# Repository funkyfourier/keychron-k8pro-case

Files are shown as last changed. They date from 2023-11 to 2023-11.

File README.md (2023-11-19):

# WIP: 3D Printable Case for the Keychron K8 Pro keyboard

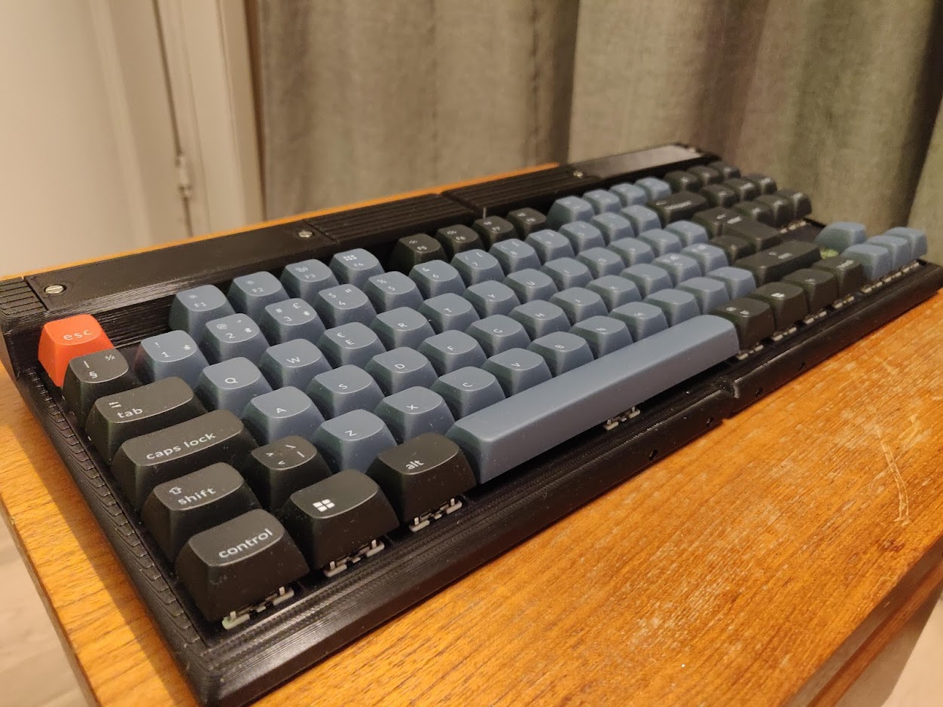
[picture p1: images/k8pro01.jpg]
Keychron K8 Pro with 3D printed case


When I got me a [Keychron K8 Pro](https://www.keychron.com/collections/keychron-k-pro-series-normal-profile-keyboards/products/keychron-k8-pro-qmk-via-wireless-mechanical-keyboard) I liked everything about it except the height. Having some CAD skills and a 3D printer I therefore set out to design my own custom case.

It has taken way much more time than I thought and is basically a product of [the sunken cost fallacy](https://en.wikipedia.org/wiki/Sunk_cost#Fallacy_effect). Still, I ended up with something I really liked and overall it has been a fun experience.

### Disclaimer

*This is to be regarded as a work in progress*, since there still are some [issues](https://github.com/funkyfourier/keychron-k8pro-case/issues) which you should be aware of before attempting to print this. At the time of writing I am not sure how much more time I am going to put into this since it already has stolen a lot of valuable time from my [other](https://github.com/funkyfourier/spitback) [projects](https://play.google.com/store/apps/details?id=info.casualcomputing.sputter).

**Important:** I have **not** dared testing using the battery yet since I do not need it personally. According to the text on the charging chip it uses the TP5000X charging IC, which I have included the [data sheet](https://github.com/funkyfourier/keychron-k8pro-case/blob/master/tp5000x.pdf) for. I am quite confident that it will work, but **do not blame me if it does not**. Also, if you need the battery, beware of [issue#7](https://github.com/funkyfourier/keychron-k8pro-case/issues/7).

**Also:** Pay attention to the polarity when you insert the battery. I do *not* know wether the board has reverse polarity protection, and the board could get fried if you insert the battery the wrong way.

### Advantages:

* Probably as low profile as it can get with a PCB and hot swap sockets.
* USB connector on backside.
* Labels for the PC/Mac and BT/Cable switches are actually visible without a lamp and magnifying glass.
* More visible screws, which is masculine and cool.
* Replaceable battery.
* Possibly better looking, depending on your taste, than the aluminium frame which [some find to be hideous](https://youtu.be/LNVKRTX5gCQ?t=504).

### Drawbacks:

* Won't do any favors to the sound of the keyboard.
* No flip out feet to adjust angle.
* Increased depth due to the compartment housing the battery and daughter board.

### In use

Even with the remaining [issues](https://github.com/funkyfourier/keychron-k8pro-case/issues) unsolved, I am quite enjoying using this as my main keyboard. Obviously it does not sound as good as in the original case, mostly due to the lack of dampening materials. On the other hand the relatively low profile without having to resort to a wrist rest and still having full travel keys makes for a pretty great experience. I have tried a [K3 Pro](https://www.keychron.com/products/keychron-k3-pro-qmk-via-wireless-custom-mechanical-keyboard) at work and definetely like this better.

Of course getting the [Keychron V3 QMK](https://www.keychron.com/products/keychron-v3-qmk-custom-mechanical-keyboard) instead is a more sensible option. I was not aware of it at the time I got my K8 Pro. Still, having the option to switch to bluetooth for my work laptop while the keyboard is plugged into my PC, and being able to switch between them quickly, is a great convenience. The V3 is probably also a couple of millimeters taller.

### Printing and assembly

The case is made in [FreeCAD](https://www.freecad.org/). If you want to adjust dimensions it should be sufficient to do that in the spreadsheets.

All parts should be printable without supports. Please rotate the models to the correct orientation in the slicer before printing.

The daughter board cover is printed with a pause command which can be set in the slicer to change the color while printing. This allows for the letters being printed in another color. If your slicer/printer does not support that the letters should still be visible.

### Bill Of Materials

* 6 M3 machine screws, max 11mm length excluding head, and max 6mm head diameter.
* 6 M3 threaded inserts.
* 4 M2 machine screws, max 5mm length excluding head, and max 3mm head diameter.
* 4 wood screws. Not quite sure about the dimensions, but mine are 4mm in diameter across the threads, 19mm length excluding head and head diameter of 8mm.
* 20mm x 5mm x 1.5mm self adhesive rubber feet
* A 21700 battery of well known brand like Molicel or Samsung.
* A 21700 battery holder [like this](https://vi.aliexpress.com/item/1005004464947052.html?spm=a2g0o.productlist.main.15.70155b8eZTWrik). **See first:** [issue#7](https://github.com/funkyfourier/keychron-k8pro-case/issues/7)
* One 2 pin ZH 1.5 JST connector [like this](https://vi.aliexpress.com/item/1005003082340140.html?spm=a2g0o.order_list.order_list_main.27.124e18027wA48)
* Cables to go from battery holder to daughter board.

## Pics

Please excuse the dust. It is amazing how clean things can look in person while lots of dust and debris still show up on camera.

**Side profile:**

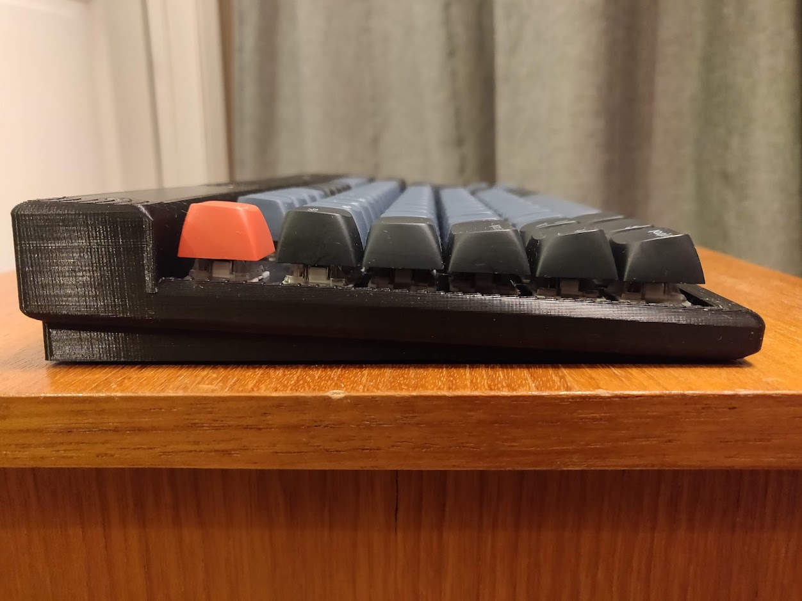
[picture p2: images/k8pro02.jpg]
Side profile


**Back side:**

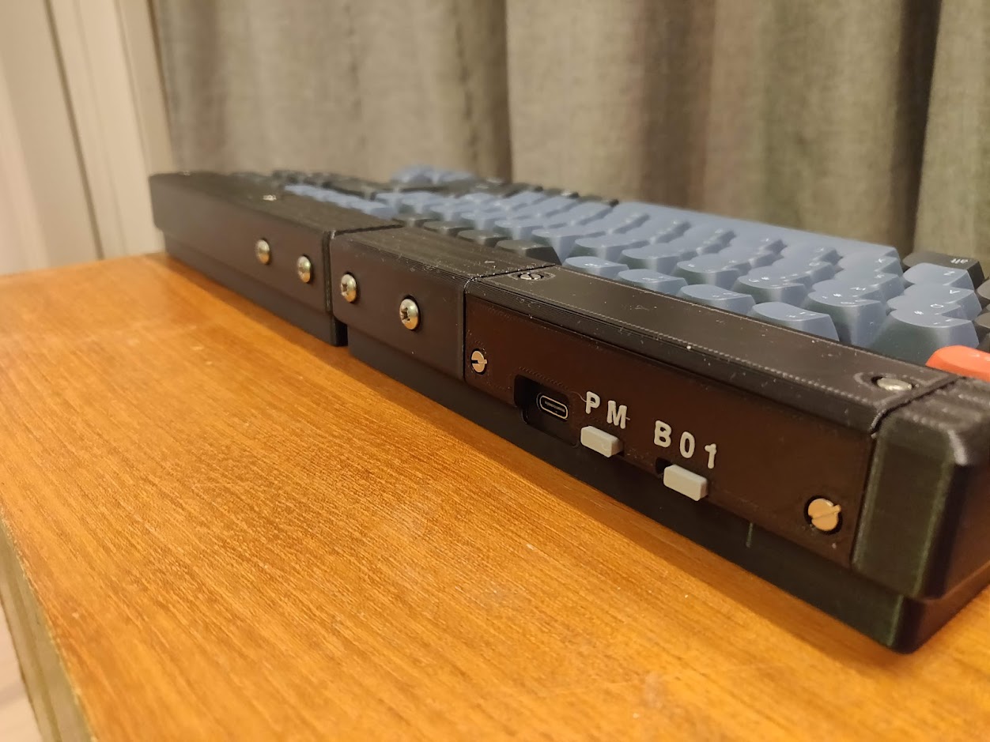
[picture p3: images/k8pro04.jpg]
Back side


**Front screws:**

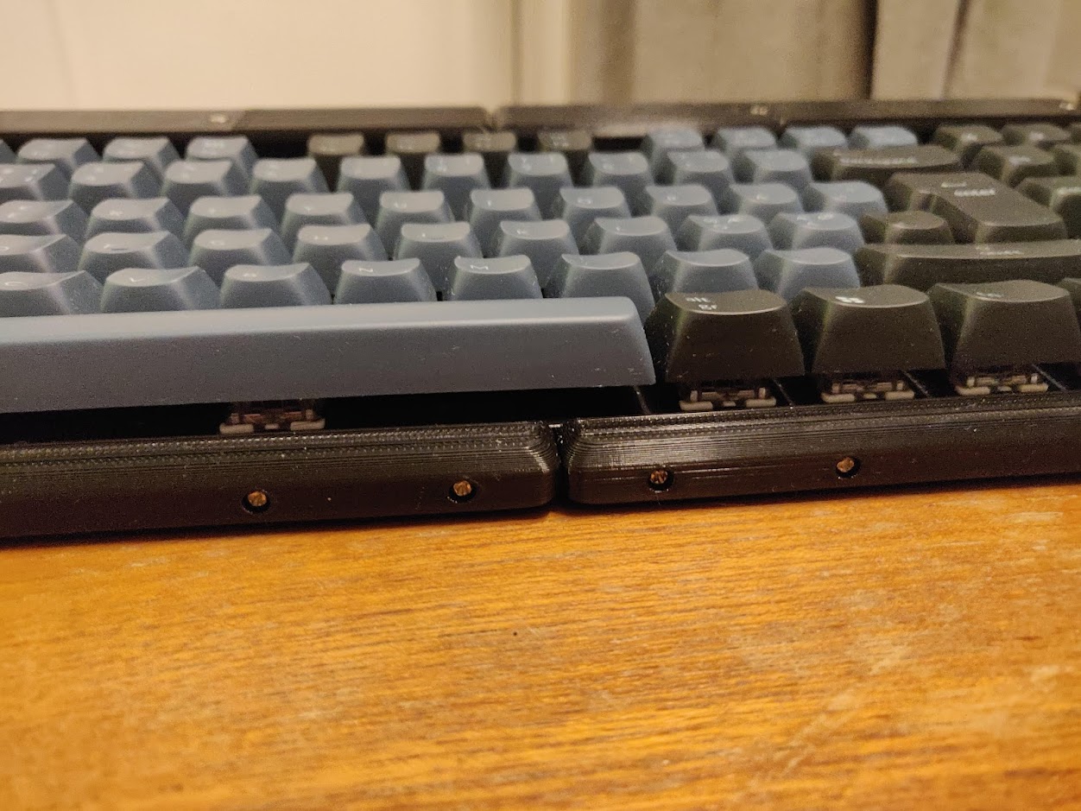
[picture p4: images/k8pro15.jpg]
Front screws


**USB plug and switches:**

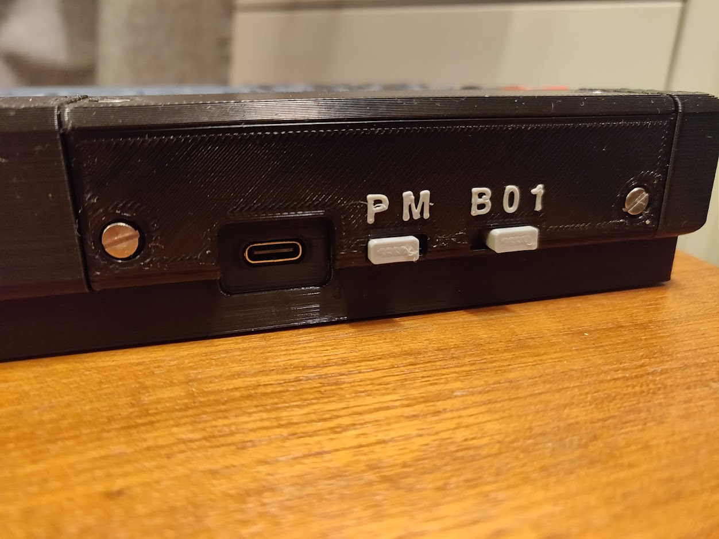
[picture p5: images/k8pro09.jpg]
USB plug and switches


**PCB partly exposed underneath:**

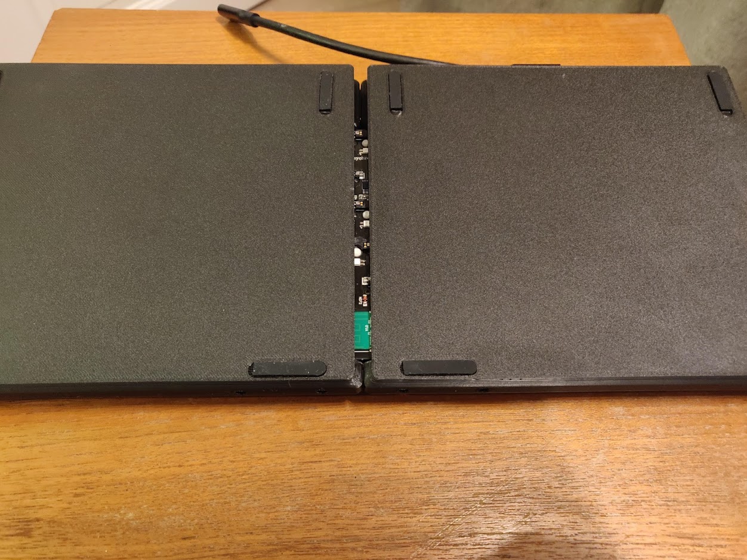
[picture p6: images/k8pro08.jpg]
PCB partly exposed underneath


**Battery compartment:**

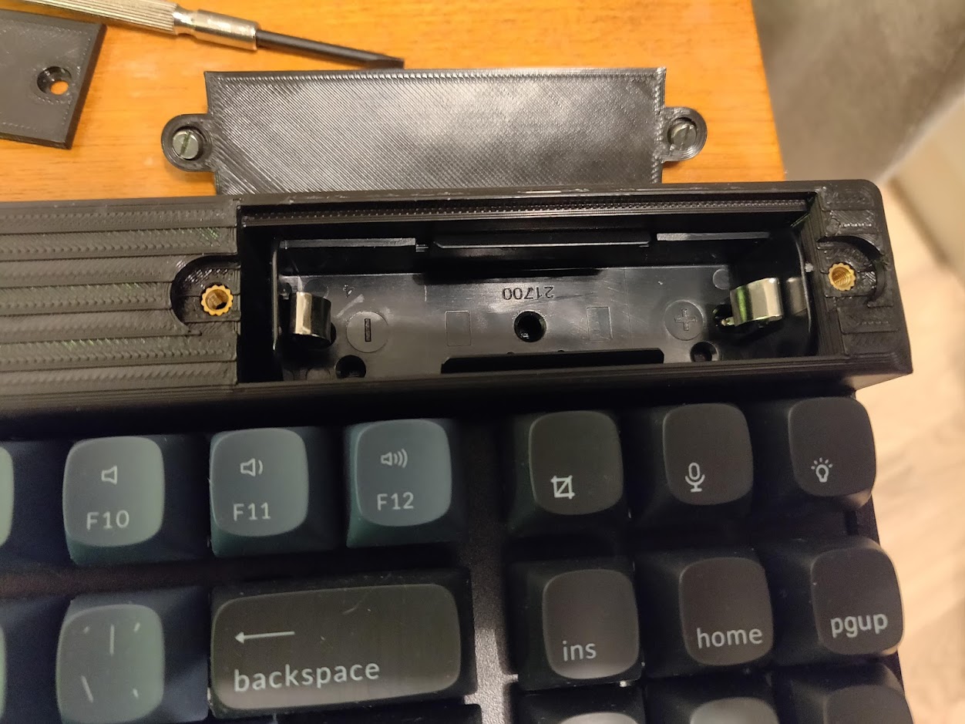
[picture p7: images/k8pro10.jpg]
Battery compartment


**Daughter board compartment:**

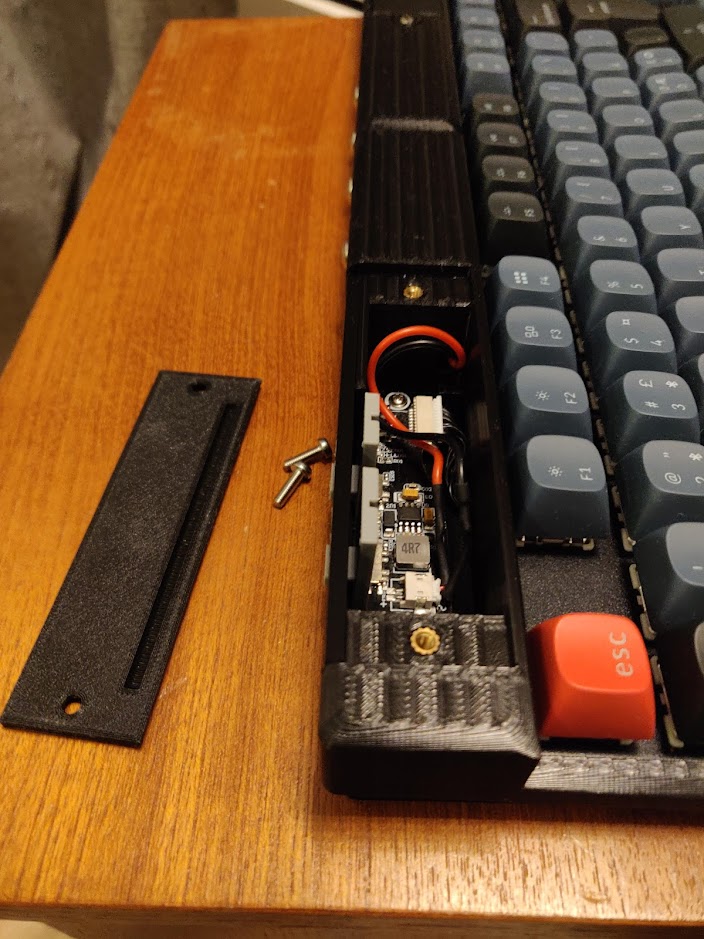
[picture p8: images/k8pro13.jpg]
Daughter board compartment


**Surface finish front:**

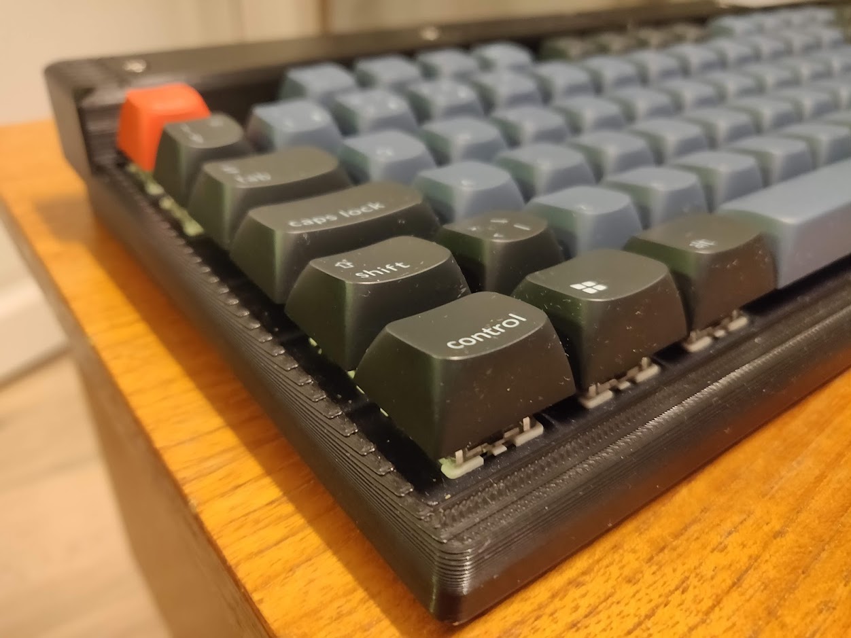
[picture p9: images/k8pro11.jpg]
Surface finish front


**Surface finish backside:**

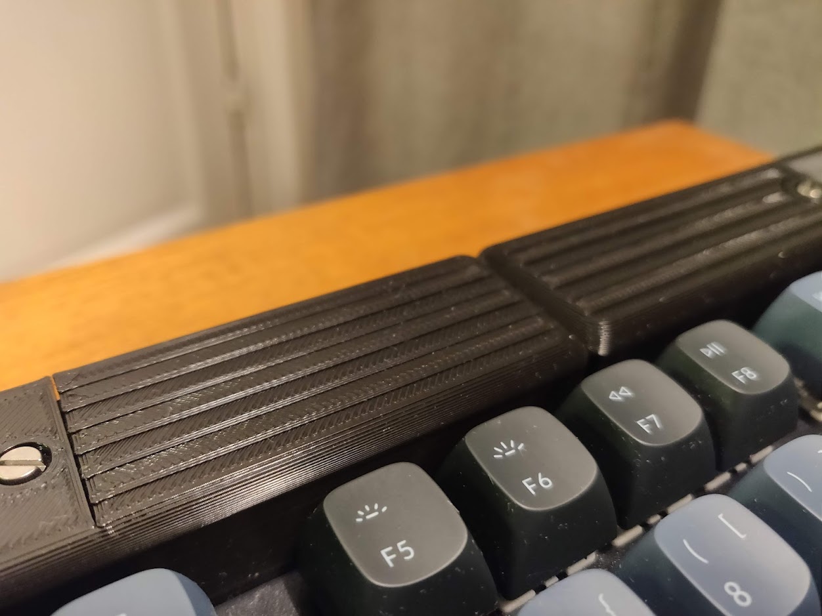
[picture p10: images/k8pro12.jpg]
Surface finish backside


**In FreeCAD, in all its glory:**

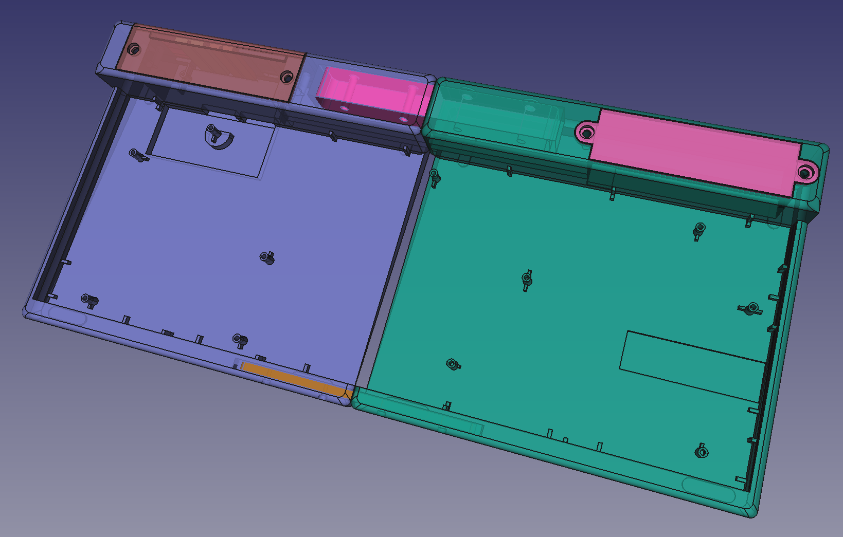
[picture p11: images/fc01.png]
In FreeCAD, in all its glory


**In FreeCAD, from behind:**

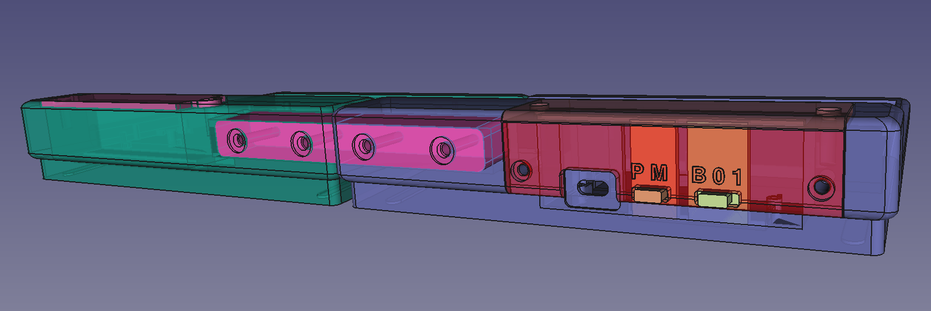
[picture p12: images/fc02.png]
In FreeCAD, from behind


**In FreeCAD, daughter board compartment:**

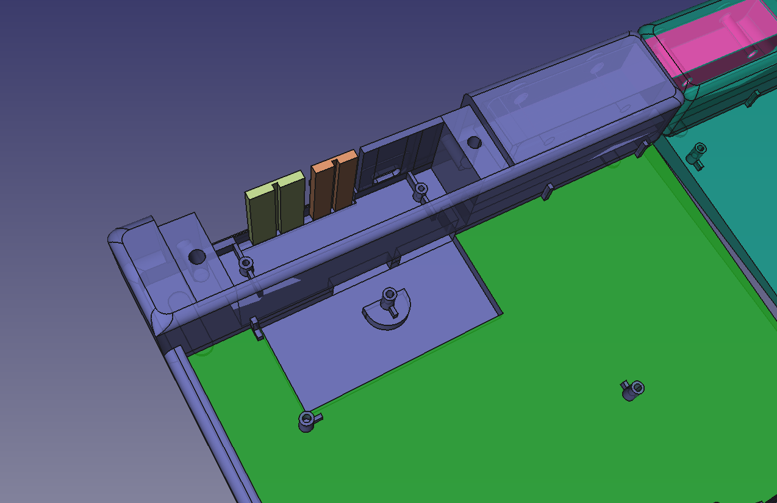
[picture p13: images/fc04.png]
In FreeCAD, daughter board compartment


**In FreeCAD, gap underneath:**

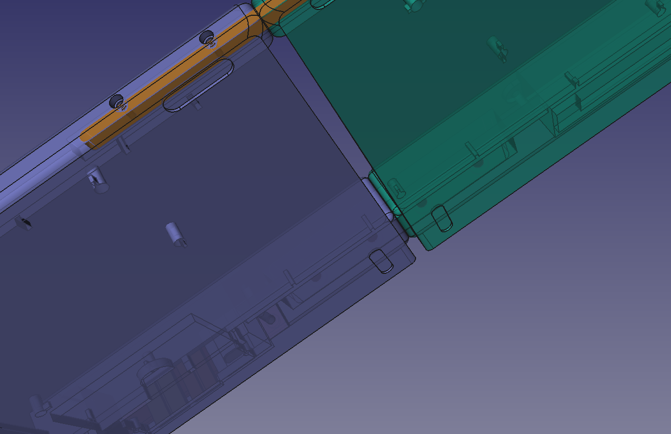
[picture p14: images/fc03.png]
In FreeCAD, gap underneath


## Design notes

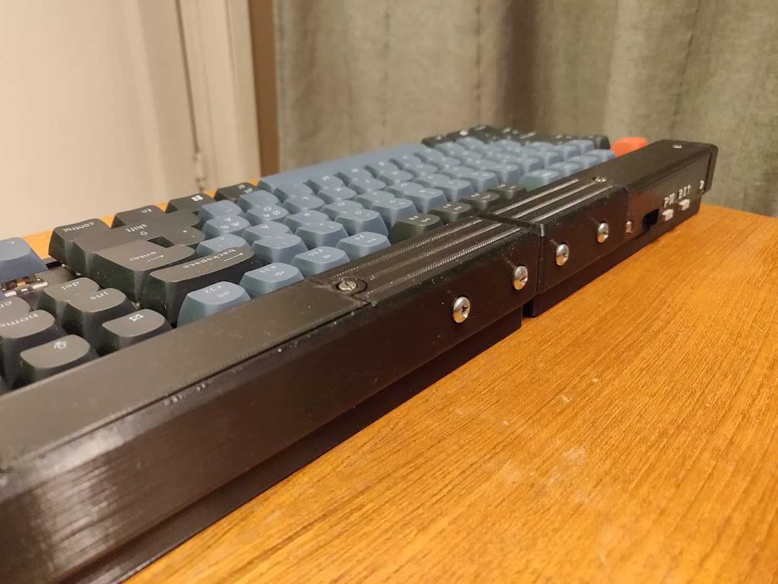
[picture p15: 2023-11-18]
images/k8pro03.jpg

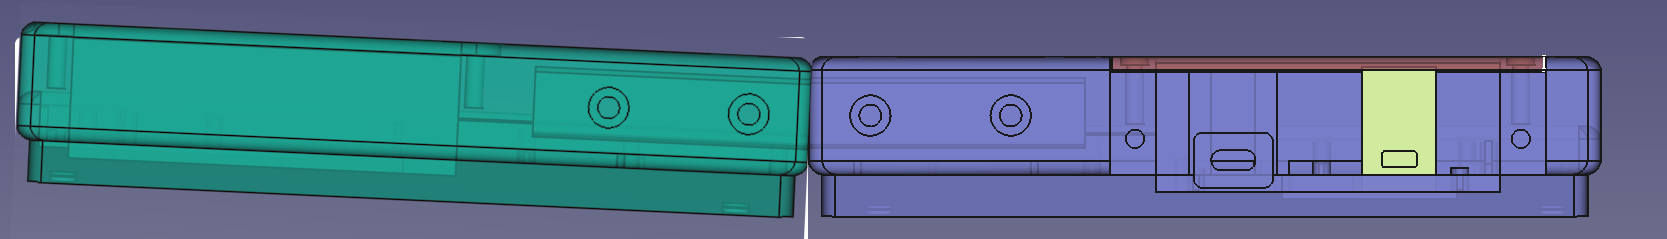
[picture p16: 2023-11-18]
images/skewed_halves.png

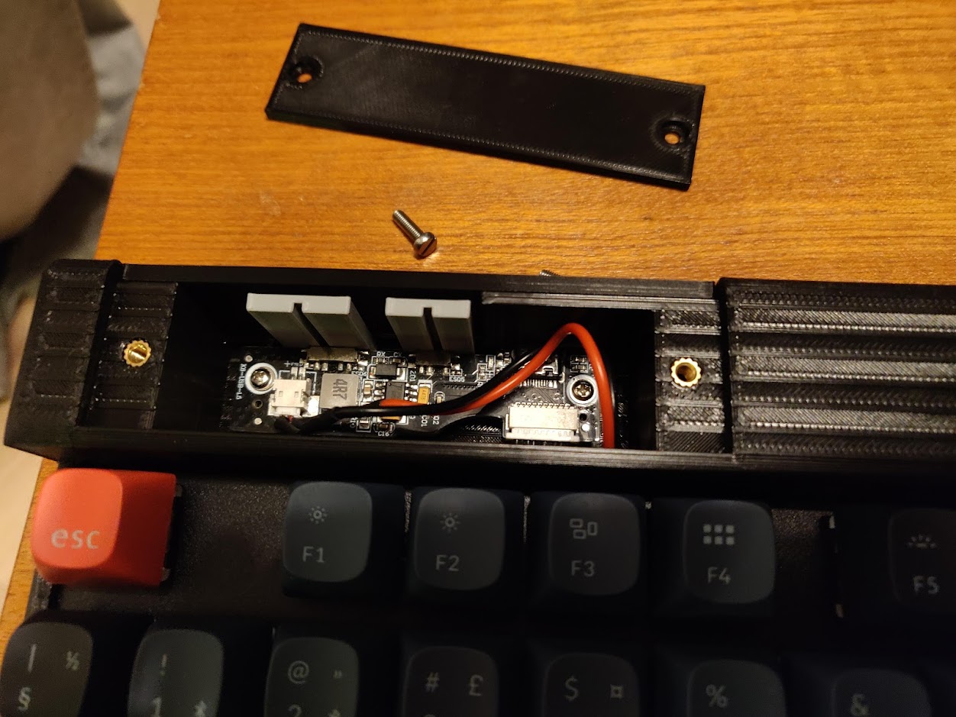
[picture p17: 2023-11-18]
images/k8pro07.jpg

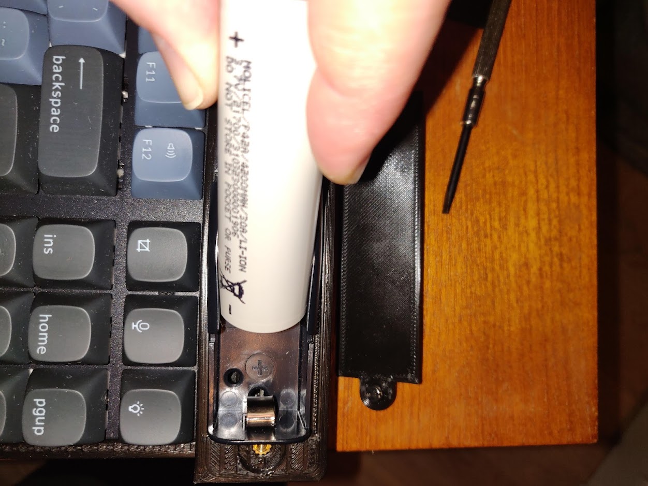
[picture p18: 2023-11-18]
images/k8pro14.jpg

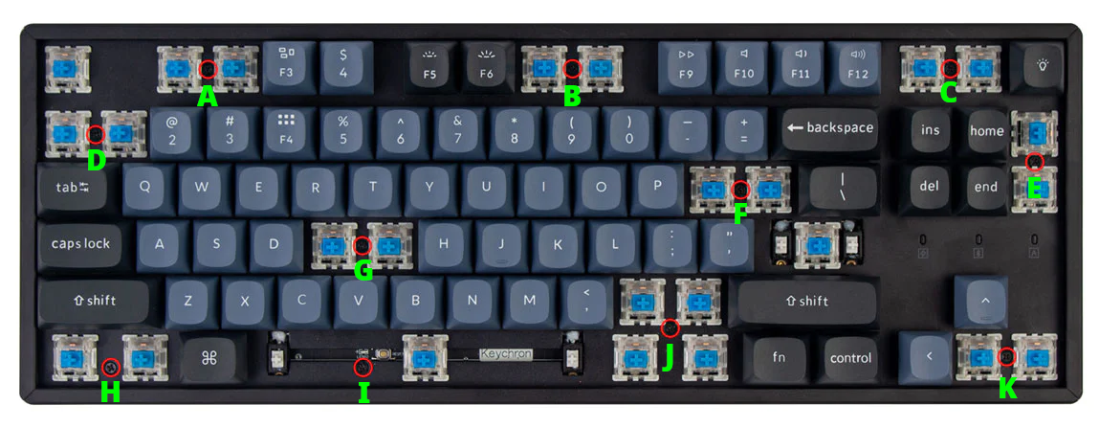
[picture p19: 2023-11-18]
k8proscrewposition.png

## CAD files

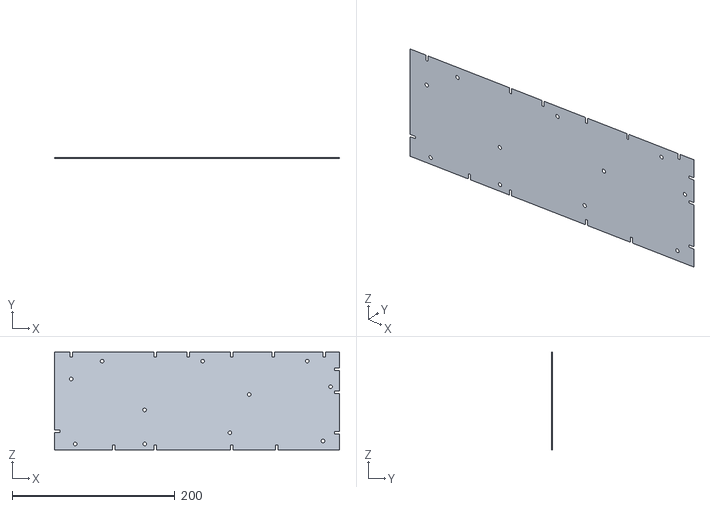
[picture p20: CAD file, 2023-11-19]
stl/DimensionsTestEdgePlate.stl
350.0 x 0.72 x 120.0

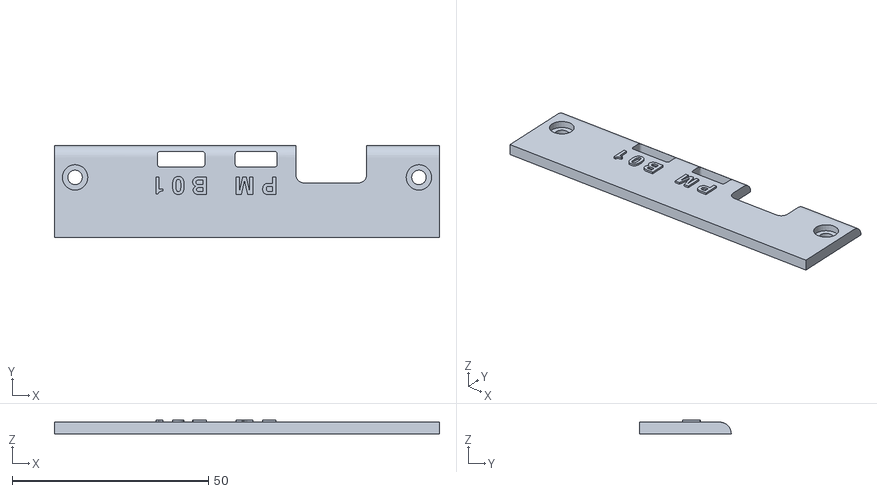
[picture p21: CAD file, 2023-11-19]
stl/DaughterboardLidBottom.stl
98.2 x 23.4 x 3.50

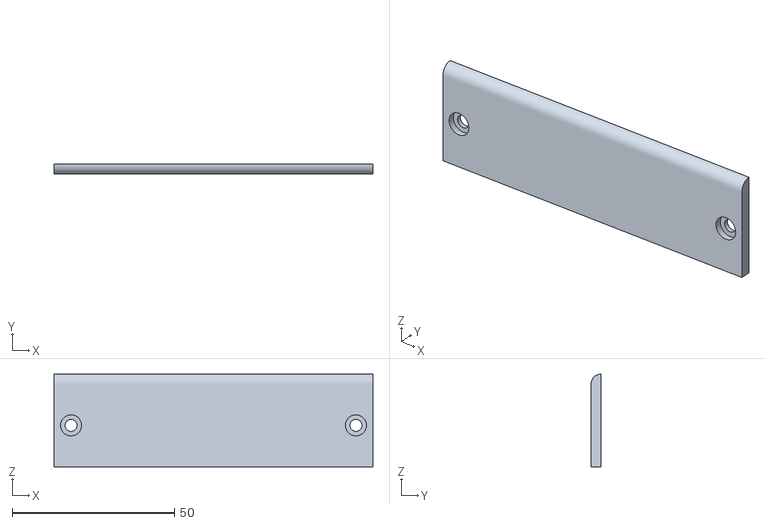
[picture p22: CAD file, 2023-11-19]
stl/DaughterboardLidTop.stl
98.2 x 3.00 x 28.6

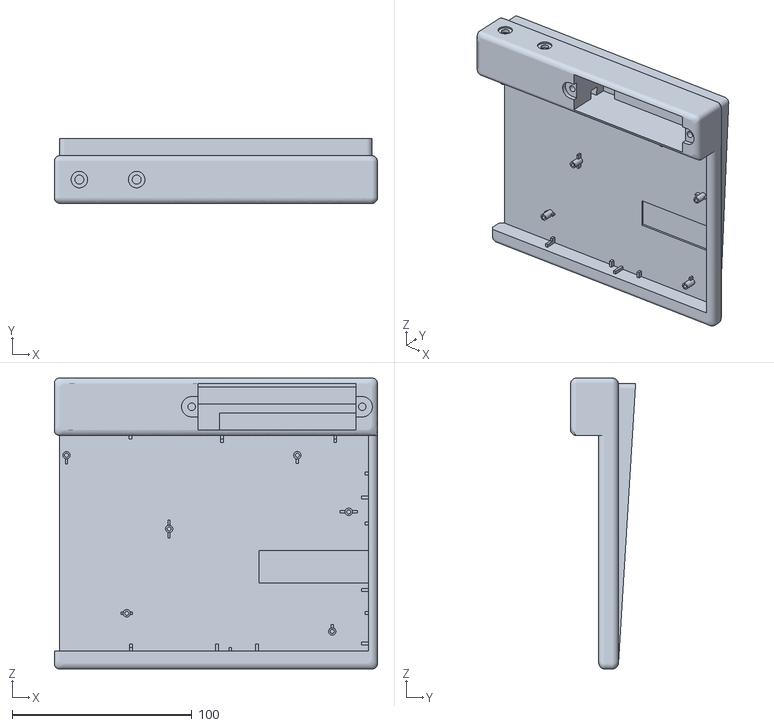
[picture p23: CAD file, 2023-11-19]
stl/BaseRight.stl
179.9 x 36.3 x 162.0

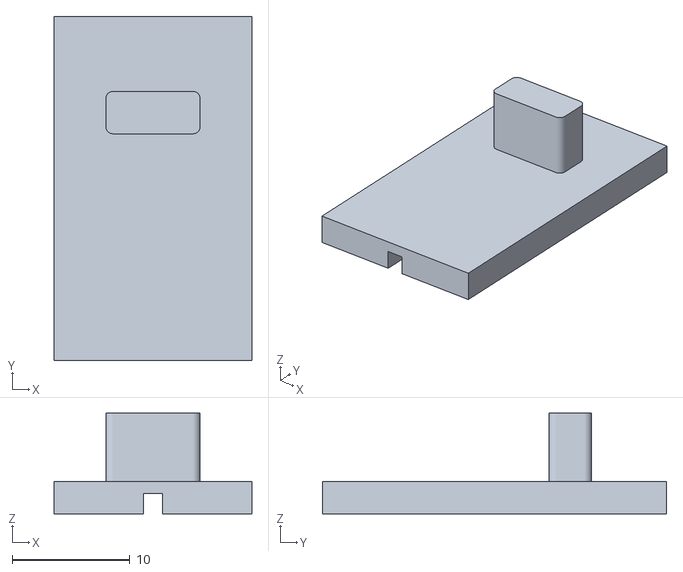
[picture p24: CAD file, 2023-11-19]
stl/SwitchBTCableOff.stl
16.8 x 29.2 x 8.55

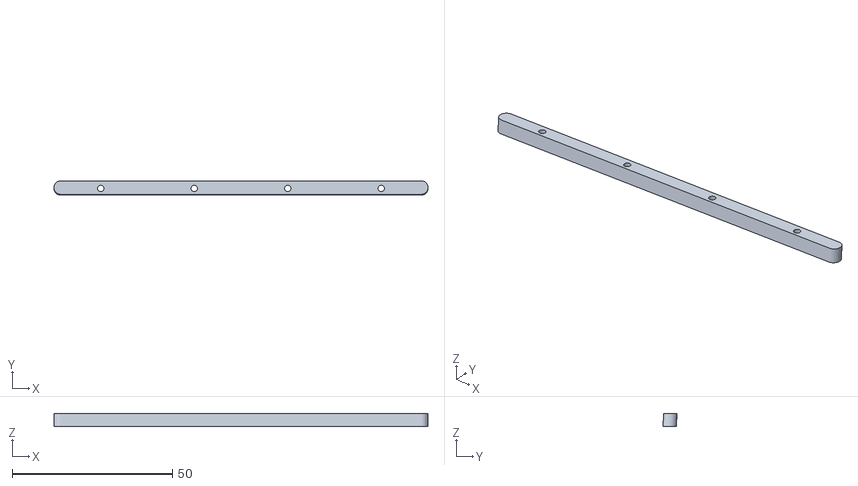
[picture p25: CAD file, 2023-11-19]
stl/FrontJointBar.stl
116.7 x 4.46 x 4.20

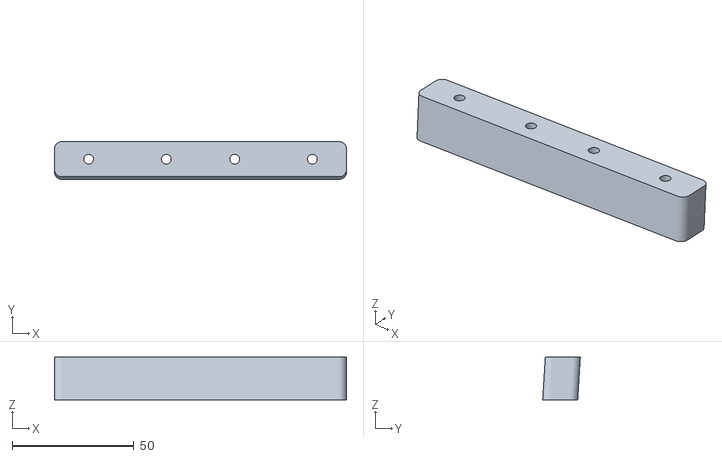
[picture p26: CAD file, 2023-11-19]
stl/BacksideJointBar.stl
119.8 x 15.5 x 17.6

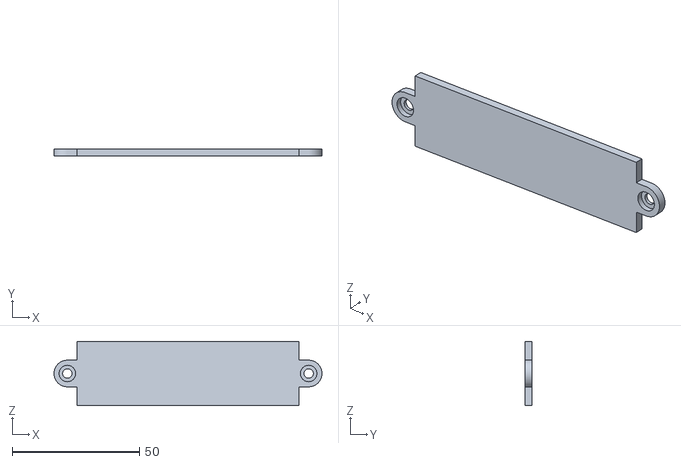
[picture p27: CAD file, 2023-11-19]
stl/BatteryLid.stl
105.5 x 2.80 x 25.2

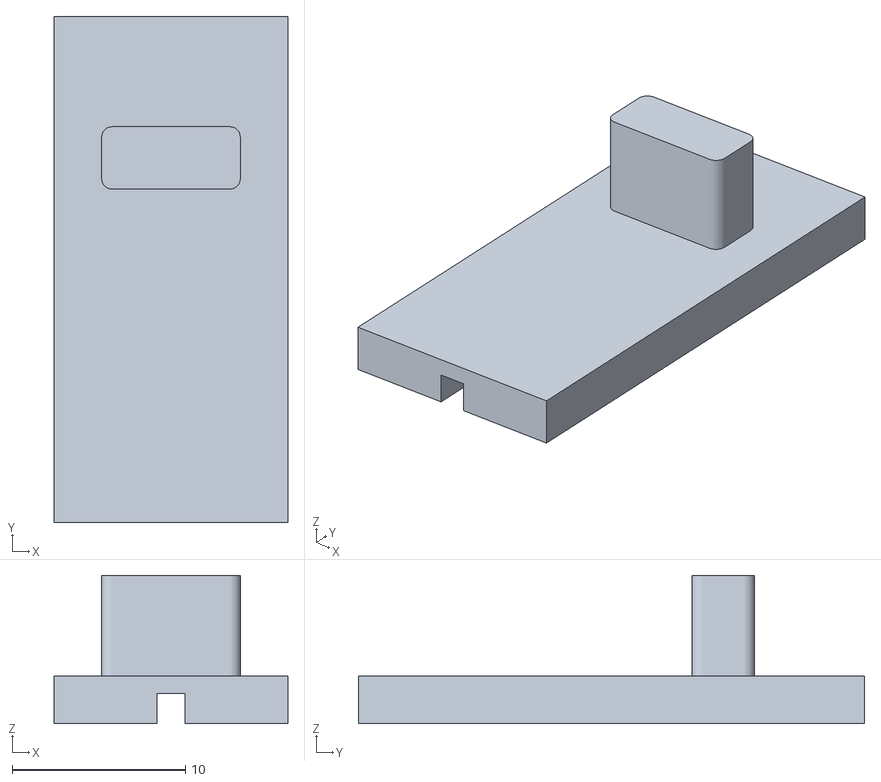
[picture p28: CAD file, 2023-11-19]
stl/SwitchMacPC.stl
13.5 x 29.2 x 8.55

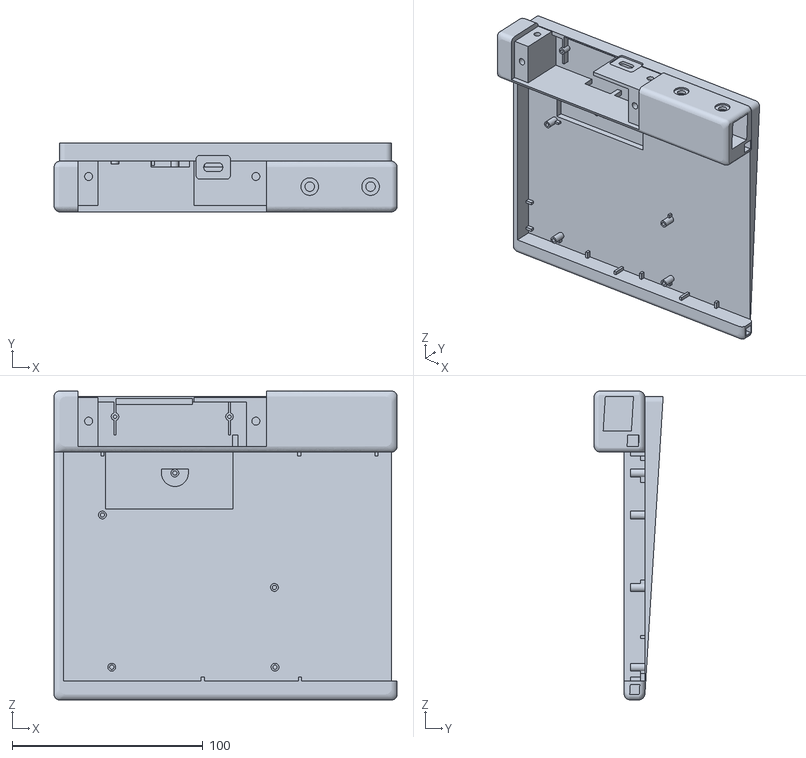
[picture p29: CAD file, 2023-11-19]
stl/BaseLeft.stl
179.9 x 36.3 x 162.0

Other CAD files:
stl/DimensionsTestEdgePcb.stl

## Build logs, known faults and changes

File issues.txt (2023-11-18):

* Height of PCB probably 1mm less
* 21700 possibly too large, might fit if widening the battery compartment
* The two parts come out slightly angled
* Mount for tablet/phone?
* Standoff F or C is a little bit out of alignment
* Rattling switches
* No angled feet
* Easier to install daughter board cable
* Close center gap underneath?

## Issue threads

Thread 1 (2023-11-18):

Two halves come out slightly skewed after mounting

funkyfourier, 2023-11-18:
After mounting the two halves they come out slightly skewed, something like this:

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

Of course this is greatly exaggerated, in my case it was only about 0.5mm or so, so I fixed it with a 0.5 mm padding under the rubber feet cutouts on one of the sides.

This can probably be fixed by increasing the tolerance of the backside joint bar and changing the screw holes of the bar to be oval (like slots), so there is opportunity to adjust the flatness when putting the frame together.

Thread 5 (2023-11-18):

Mount for phone/tablet

funkyfourier, 2023-11-18:
There could easily be a mount for tablets or phones on the backside bar. Probably the area between the battery and daughterboard compartments would be too narrow, especially for tablets, but an external mount on the backside mounted with screws would be ideal.

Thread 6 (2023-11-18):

Slide switches are rattly

funkyfourier, 2023-11-18:
The tolerances of the slide switches (BT/Cable/Off, Mac/PC) are too large, making them rattle quite a lot. This is quite hard to get properly right on 3D prints.

I have ordered switches like these, we'll see if I dare to attempt to solder them in:
https://vi.aliexpress.com/item/32958308389.html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

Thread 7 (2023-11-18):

Battery holder needs to be replaced

funkyfourier, 2023-11-18:
The battery holder used in my print does not work since the flaps on the sides stick out beyond the walls of the compartment.

This is the one I am using:
https://vi.aliexpress.com/item/1005004852731607.html?spm=a2g0o.productlist.main.1.70155b8eZTWrik (single version)

It needs to replaced probably with something like this:
https://vi.aliexpress.com/item/1005004464947052.html?spm=a2g0o.productlist.main.15.70155b8eZTWrik (single version)

Probably this requires modifications to the case. Also: Can it be fastened with screws instead of glue?

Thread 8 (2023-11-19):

Daughter board plug is hard to install

funkyfourier, 2023-11-19:
Would be nice having a bit more room for connecting the cable from the main PCB to the daughter board. Right now it is doable but pretty hard and requires tweezers.

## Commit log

2023-11-18 Testing zippey filter
2023-11-18 Better image of daughter board compartment
2023-11-19 Added STLs and updated README
    [BacksideJointBar.stl, BaseLeft.stl, BaseRight.stl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]
